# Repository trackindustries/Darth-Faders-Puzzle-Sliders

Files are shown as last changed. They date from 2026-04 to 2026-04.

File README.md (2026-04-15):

# Darth Faders Puzzle - Build/Install Guide
The Darth Faders Puzzle Trigger online guide explains in great detail the hardware, software and wiring for this project. We encourage you to read this first to get comfortable and familiar with the project and it's components.

## 3D Models
There are 7 pieces to the project
1. (1) Base
2. (1) Body
3. (1) Cap
4. (1) Crown
5. (3) Button Frames 

##Build
1. Install necessary library a board objects to Arduino IDE, and upload code to your RP2040.
2. Separate and pull apart all your jumper pins. (For example, you’ll need 4 each of Yellow, Red and Green, 4 Orange, 10 Black, 3 Brown, 1 Blue, 1 Purple, 1 White)
3. Remove the plastic housing from one side of each wire (use the tip of an exacto blade to lift up the small center tab and the casing slides right off). Then using your wire snips to snip off the aluminum pin just past the widest part closest to the wire. This will leave a short metal stub that will fit PERFECTLY inside the terminal holes. It create a tight and solid fit while keeping the integrity of the wire in tack and leave you with a sharp pin on the other to solder in all the through holes of the PCB’s and pins.
4. Solder your BUCK Converter to your Breakout board. Look at the bottom of your breakout to find the ground rail that runs across an entire row.f you put your 2 pin terminal block on that end and you place your buck just below that row, it’s easy to connect your OUT- and IN- to the GRN row and then up to one of your terminal pins. All that’s left is connecting OUT+ to USB hole, and IN+ up to the other pin on your terminal block.
5. Use volt meter to double check voltages. Should have 5v coming out of OUT+. OUT+ should be connected to USB. THIS IS CRITICAL. We do not want to connect the stack and later try to power the RP2040 with the 9v Power supply if this converter isn't properly connected!
6. Solder up your wires to your Sliders. I used colored wires on the center wiper pins so I could ensure I knew which slider goes to which color. Used Red for left pin (3.3v) and black or brown for GND pin up on the top side near the motor.
7. For each motor also use Black wire for one side and either a Red, Green or Yellow wire for the other pin. You will now have two Red, Yellow or Green wires coming off each slider/pot. One for the motor feather, and the other for A0, A1, and A2 pins on the breakout. 
8. Use small shrink tubes to keep things tidy. I used 3 (Top middle and bottom) to connect/group the 3 slider Grounds, 3 to group the 3.3v power lines, and 3 to connect each set of motor wires. This creates a sort of ‘slider chassy’ to keep your wires under control
9. Solder your Step Switches to their PCB Boards.  You’ll have 4 wires coming off each step switch PCB (A black LED-, a Brown Common and either RED, GREEN or YELLOW wires for both the LED+ and N-OPEN pins (mark the end of LED+ with black marker or piece of tape. I group the Commons together and the LED- wires Together. (Again using 3 small shrink tubs one near the pin connections to the PCB, one in the middle, then one near the other end (making sure not to get to close to the end as they need to separate) and do the same for the two colored wires ( LED+ and N-OPEN) from each button/PCB. (This is why we mark/identify the LED+ wire) 
10. Solder wires to your I2C backpack. Red Power, Black GND and Yellow and Orange for Clock and Data (or any other colors for that matter)
11. Now it’s time to wire it all up. Take extra care to get wires to the correct pins. They don't mark the breakout board with the RP2040 numbers so It takes effort to find the right one.
12. Use wire terminals to get your Ground wires down to three wires 
    1. Ground #1 (common lines from step switches
    2. Ground #2 (LED- lines from step switches, the GND line from momentary button and GND line if for your trigger line (if you need to access the trigger on success)
    3. Ground #3 (GND Lines from Sliders)
13. Use a wire terminal to group your 3.3v power lines from your sliders together 
    1. 3.3v #1 (power lines from the 3 sliders)
    2. 3.3v #2 (power line from I2C Backpack
14. Wire to breakout based on documentation leaving the 6 motor wires last (2 for each motor)
15. Plug RP2040 in to breakout.
16. Plug Motor Breakout in to RP2040.
17. Wire the motors to M1, M2 and M3 (Referring wiring diagram for proper terminals.
18. Screw the Motor ends of the sliders to the base of the model using M3x6 screws. Green left, Yellow Middle, Red right and set breakout on pins to hold in place.
19. Have Arduino IDE open with Serial Monitor set to 15500)
20. Ensure you have not yet connected your two 2 pin power terminals together (Motor breakout and BUCK). This will be the very last thing after all troubleshooting 
21. plug in 9v barrel 
22. Plug in USB-C.
23. Watch your Serial Monitor. Troubleshoot as needed (see troubleshooting section)
24. Once everything is working, unplug all power. Run wire from Motor Breakout + to + terminal connected to Buck. Do same for GND.
25. You should now be able to plug the 9v Barrel in and everything should run (you will not have access to serial monitor now). Run voltage tests on breakout (i.e. USB pin) with stack removed before connecting stack and powering by 9v to ensure 5v is being delivered to USB pin when 9v power is supplied to Motor breakout.
26. Finish assembly of model. Place BODY down in position of BASE
27. Pull the three button assemblies up though the top and screen in to place using M3x6 screws
28. Insert buttons in to openings of CROWN keeping color the same orientation as the sliders.
29. Use the Button frames to keep buttons in place using super glue as needed (TAKE EXTREME CARE to not get glue on button hinge, terminals or springs.
30. Use super glue to carefully glue CROWN to CAP TAKING EXTREME CARE not to use too much glue so that it seeps out edges. A few dots on each corner should be sufficient.
31. Glue Numeral Display to Backpack TAKING EXTREME CARE not to exceed past or overlap in the path of the Yellow slider path. 
32. Ta Da! Your done. Take pride in your Darth Faders Puzzle Trigger project.

## Lessons Learned
LESSONS LEARNED:

First, I was really struggling with the pins on the motorized sliders. Not sure why because looking at the data-sheet it’s very clear. I just saw other things that contradicted it and made it more complicated than it needed to be and they really don't articulate what pin is what in the Darth Faders project. Wont bore you with all the super gory many hours of details, but finally sorted it out. If you’re looking at the back of the slider with the motor at the top. The GROUND pin is on the top left side next to the motor (Strange place for it, but is what it is). The POWER pin is on the bottom left, the WIPER pin is in the middle, and the touch pin is on the bottom right (Not using this pin in my project). Do not swap the GND and POWER pins. If you do, the auto calibration routine on start up wont work right and you’ll get some cooky LED action happening. (PART OF MY STRUGGLE)

The breakout board has a 3 GND ports. We should use them all. Use a different GND port for each group of grounds. IN other words, put the 3 grounds for the step switch LED wires (along with the GND wires from the button and the Backpack) on one GND port, the 3 Common wires from the step switches on a separate GND port, and the ground wires from the sliders on a 3rd GND port. Don’t group all your ground wires together. You’ll get some icky LED wiper readings and Backpack LED behavior when you do that (PART OF MY STRUGGLE). 

This one is obvious but it’s worth a gentle reminder: Make sure you check all your solder points on your PB85 breakout boards for your switches, and make sure you use the Normally Open pin(NO-O).  The Normally Closed (NO-C) pin should be empty. (PART OF MY STRUGGLE) 

You must solder the A0 pins together on the backpack to change the address. If you don't, you’ll get a conflict with the motor breakout. The pins on the backpack go on the top when mounting in its opening on the model. (If you put it in upside down, the counter will go top to bottom instead of bottom to top. ) it’s designed so #1 is at the bottom and #24 is at the top. 

If you dig in to the code, you’ll may see there are some functions on the Motor.cpp file that aren’t used(tried cleaning them up). I tried to do some fancy slider dancing on a successful puzzle solve, but couldn’t get the sliders to get to the middle of the track correctly. I’m sure there was a better way of doing it, but just didn’t happen. As such the sliders do a quickly little UP->DOWN-> dance on success. 

IF you need to troubleshoot, MAKE SURE you don't have the BUCK converter powering your RP2040. You’ll need the 9v barrel power to power the motors and the USB-C plugged in to your RP2040 to see the serial port data. If you plug both of those in AND have the BUCK converter taking power from the 9V power and feeding the RP2040, you’ll make smoke and be sad.

I soldered the buck converter to the available breakout pins on the breakout board. It’s really nice they developed it so you can put additional components on the Breakout board when you need. (We need). I then used breadboard jumper wires to neatly connect things together. My soldering job was just pitiful but worked none the less. Soldering the BUCK to the Breakout makes things nice and tidy because we are going to have a *#&$^% ton of wires when this is all done. We don't need yet another object floating in space.

I put a 2 pin port block on the end of the breakout to give me easy access to IN power and ground on the BUCK
Soldered jumpers from one pin to IN+ and one pin to IN-
OUT- and IN- I ran to the GND rail that runs across the bottom (look at the bottom of the breakout board labeling to find it)
The OUT+ goes to USB.
I had to undo it once because I soldered things backwards. The BUCK is labeled on the bottom so when looking at another for reference, my brain flipped things and I soldered things wrong. (PART OF MY STRUGGLE) Now I just have to run to wires from the 2 pin Port Block on the Motor Breakout to the 2 pin Port block on the Bottom Breakout board. 
This means two wires are going in to the power Ports on the Motor Breakout. Coming IN from the Barrel port, the OUT to the BUCK.
I did all this so we could just use the 9V barrel power instead of needing both cables.

Make sure you use long enough wires to connect things together. You’ll board the struggle bus if things are too short or exactly the right length. Make things longer then user good wire management to clean things up (zip ties and heat shrink tubes)

##Troubleshooting

If your Backpack LED's are only lighting up a short distance:
 (i.e. only 6 high for example) you likely have your wiring wrong on your sliders. Check your ground connections, make sure the left wire is wired to 3.3v and GND to GND, and center pin is your wiper pin connect to the correct pin corresponding to that correct color. Also make sure on boot up that the High = Highst value, and Min = Lowest value. If these are backwards, things wont work.

If your LED Backpack matrix isn't working:
Make sure you have connected/soldered the A0 pins together on the back of the Backpack to change it's address. Out of the box, both it and the motor feather have the same I2C address.
Make sure you have Data to Data and Clock to Clock 

If your motors arn't working:
Make sure your motor feather has power (should have a green LED)
Make sure it's security stacked on top of your RP2040 (no pins are bent or missed their connection hole)
You have them connected to M1, M2 and M3 ports (GND wires should be in the middle connectors and the color wires (Red, Yellow and Green) should be on the outer ends.

If things don't work after connecting BUCK to breakout:
Remove the stack from the breakout.
You should have done a voltage test on the BUCK before you connected anything to it ensuring the OUT+ is sending 5v and that it's connected to USB.
Make sure you dont have solder gaps or bleeds.
Wire the 9v Barrel port directly to the breakout with the stack removed. Plug in the power and run your voltage tests again. IN+ should be 9v, OUT+ should be 5v.
Test the USB by connecting your probes to GND and the USB screw on the breakout. Should be 5v
Test to make sure you have connections between OUT+ and USB, as well as OUT- to ground.

## Quick Operation Reference

SET THE CODE
1. No step switches pressed + hold momentary 5s -> SET mode (all LEDs blink fast)
2. Press a step switch -> blinks slow -> move slider to select code -> bargraph fills that color
3. Press same switch again -> locked (LED solid, single bargraph LED lit)
4. Repeat for remaining two colors
5. Press momentary once -> saved -> celebration sequence -> IDLE

SOLVE THE PUZZLE
1. Press any step switch -> blinks slow (solve mode)
2. Move slider -> bargraph fills in that color
3. Press same switch -> locked (LED solid)
4. Repeat for other two colors (any order)
   CORRECT -> celebration + 3s HIGH on GPIO37
   WRONG   -> all off + sliders reset to bottom -> IDLE

REVEAL STORED CODE
1. Press each step step switch once -> all blink slow
2. Hold momentary 5s -> sliders move to stored positions, bargraph shows values
3. Press momentary once -> sliders return to bottom -> IDLE

FACTORY RESET
Hold momentary 10s (no switches in solve mode) -> code resets to 7/7/7 -> IDLE

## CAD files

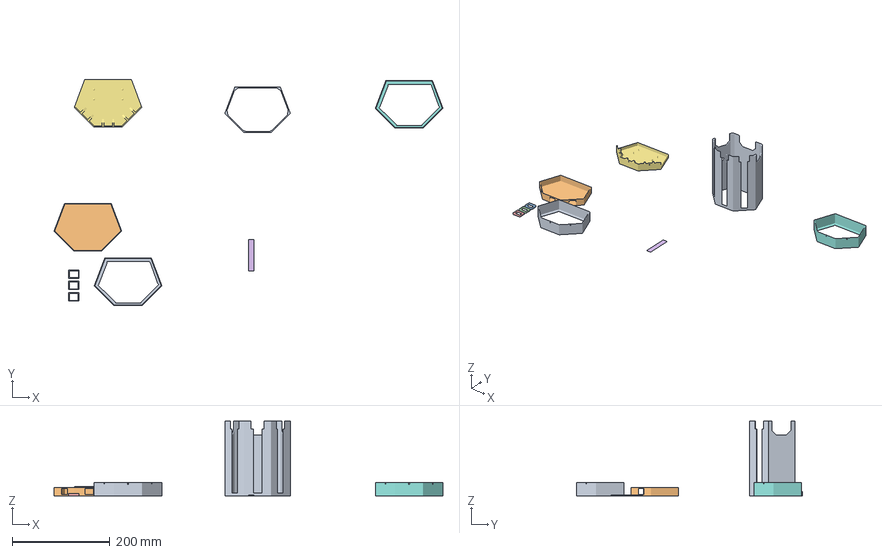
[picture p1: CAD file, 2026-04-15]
Darth_Fadters_Puzzle_Trigger.3mf
797.2 x 463.7 x 152.8 mm
fader_walls.stl
fader_top.stl x 3
Cube_A
fader_base.stl

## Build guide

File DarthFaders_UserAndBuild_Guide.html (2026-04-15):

Menu

# Darth Faders Puzzle/Trigger

A 3-slider motorized puzzle using a Feather RP2040, motorized slide potentiometers, a bi-color 24-bar bargraph, and color-coded step switches which trigger a 3.5v signal to a dedicated pin to initiate or trigger another device. We used this as a way to unlock a secret door in our home. You could also use this as a puzzle in an escape room. Based on the Adafruit Darth Faders project (https://learn.adafruit.com/darth-faders/build-the-darth-faders) by John Park. You can use that project for a guide to set up. We have not modified their 3D files, only added a top crown unit to hold the stepper switches and number plate for backpack. You can download the entire 3D print file bundle in our GitHub repository mentioned later in this project

CODE: C++ CONTROLER: Feather RP2040 LOE: High; 8+ Hrs 3D PRINTING: Yes SKILL LEVEL: Moderate

ℹ️

MOD/BRANCH IDEAS: The selected motorized sliders have a touch pin. This means if you utilized a capacitive slider knob, many of the functions which use the stepper switches could be eliminated simply by touching the slider.

🎛️

## Introduction

Three motorized sliders each represent a value from 1–24. Players must move each slider to the correct position and confirm it using the matching colored step switch. When all three values match the stored code, the puzzle triggers a success output on a designated GPIO pin.

An admin (momentary) button enables setting a new code, revealing the current code, and factory resetting — all without modifying firmware.

ℹ️

The solve code is stored in flash via the EEPROM library (built into the Arduino-Pico core) and survives power cycles and firmware re-uploads (unless you erase all flash).

🛒

## Bill of Materials

Materials below include Adafruit part numbers.

Feather RP2040

Main MCU. USB-C, 3.3V logic, I²C, ADC.

#4884

DC Motor + Stepper FeatherWing

I²C motor driver. M1=Red, M2=Green, M3=Yellow.

#2927

Motorized Slide Potentiometer

10kΩ pot + DC motor. Qty: 3.

#5466

Retro Step Switch with LED

One red, one green, one yellow. Qty: 3.

#5517

PB86 Step Switch Breakout PCB

Breakout board for each step switch. Qty: 3.

#5631

Bi-Color 24-Bar Bargraph I²C Backpack

I²C addr 0x70. Supports RED, GREEN, YELLOW.

#1721

Terminal Block Breakout FeatherWing

terminals for all signal connections.

#2926

DC Barrel Jack (2.1mm)

9V power input to Motor FeatherWing.

#610

9VDC 1000mA Power Adapter

Single power source for motors and board.

#63

MPM3610 5V Buck Converter

Steps 9V Power supply down to 5V.

#4739

Momentary Button

Hidden admin button for SET / REVEAL / RESET.

#1445

Stacking Headers

12-pin and 16-pin female headers

#2830

Potentiometer Nubbin

Rubber Slide Nubbin (pack of 3)

#5621

Resistors

100Ω resisters (use alternate valued resisters for brighter/dimmer LED's)

#4293

12" Jumper Wires

Primary wires for easy and secure component connections.

#760

Schematic

## Wiring Diagram



📦

## Libraries & Board Setup

Install the following via Arduino IDE → Tools → Manage Libraries:

Library | Notes
Adafruit Motor Shield V2 | Controls DC motors via I²C Motor FeatherWing
Adafruit LED Backpack Library | Drives the 24-bar bargraph display
Adafruit GFX Library | Dependency of LED Backpack
EEPROM | Built into Arduino-Pico core — no install needed. Stores solve code in flash.

For the board, install the Raspberry Pi Pico / RP2040 board package by Earle Philhower and select Adafruit Feather RP2040.

🔩

## Feather Stack Assembly

Stack the boards in this order, bottom to top, using stacking headers:

Position | Board | Adafruit # | Notes
Bottom | Terminal Block Breakout FeatherWing | #2926 | Provides screw terminals for all external wiring. 5V USB input from DC Buck converter to USB pin powers the RP2040.
Middle | Feather RP2040 | #4884 | MCU; USB-C for programming. Powered via Terminal Block USB pin in field.
Top | DC Motor + Stepper FeatherWing | #2927 | I²C motor driver; receives full 9V from barrel jack. This is placed on top for easy access to wire terminals

⚠️

Do not use the 9V power supply and the 5V USB at the same time when Feather Stack is assembled! You should use the USB-C for programming and/or troubleshooting, then switch to the 9V/BUCK input supply for field use, or disassemble Feather Stack to use both power sources.

🔌

## Pin Assignments

### Slider Potentiometers

Each motorized slider has 5 connections: Motor+, Motor–, Wiper (ADC), Track-Top (3.3V), Track-Bottom (GND).

Slider | Motor+ | Motor– | Wiper → RP2040 | Track Top | Track Bottom
Red | M1A | M1B | A0 [GPIO26] | 3.3V | GND
Green | M2A | M2B | A1 [GPIO27] | 3.3V | GND
Yellow | M3A | M3B | A2 [GPIO28] | 3.3V | GND

### Step Switches via PB86 Breakout

ℹ️

INPUT_PULLUP is enabled in firmware — no external pull-up resistors needed on switch pins. Add a 100–220Ω resistor in series with each LED+ line.

Switch | Input Pin (SW+) | LED Pin (LED+) | SW– / LED–
Red | D12 [GPIO12] | D11 [GPIO11] | GND
Green | D13 [GPIO13] | D9 [GPIO9] | GND
Yellow | D10 [GPIO10] | D6 [GPIO8] | GND

### Momentary Button

Connection | Pin
One leg | D5 [GPIO7]
Other leg | GND

### Bargraph I²C Backpack

Backpack Pin | RP2040 Pin
SDA | SDA [GPIO2]
SCL | SCL [GPIO3]
VCC | 3.3V
GND | GND

I²C address in use: 0x71 — set in config.h as BARGRAPH_ADDR.

⚠️

A0 solder jumper required. The backpack ships with a default address of 0x70, which conflicts with the DC Motor FeatherWing (#2927) on this build. To resolve this, bridge the A0 jumper on the back of the bargraph backpack — this shifts the address to 0x71, which is what BARGRAPH_ADDR in config.h is set to. If you ever swap or replace the backpack, remember to bridge A0 before powering up.

### Trigger Output (Correct Solve)

Signal | Default Pin | Behavior
Trigger | D24 [GPIO24] | HIGH for 3 seconds on correct solve

⚡

## Power

A single 9V barrel jack powers the entire project. A DC buck converter splits that supply into two paths — full 9V to the motor breakout board, and a regulated 5V to the RP2040.

Source | Connection | Powers
9V Barrel Jack | Motor FeatherWing VIN + GND | DC motors (full 9V)
9V Barrel Jack → Buck Converter → 5V out | USB port on Terminal Block FeatherWing | RP2040 + all logic
USB-C on RP2040 | Direct to RP2040 | Programming and development only

ℹ️

Buck converter setup: If using a multi variable output Buck converter, ensure you set to exactly 5V before connecting it to the Terminal Block USB input. Most Buck modules have a small trim potentiometer — use a multimeter to confirm the output voltage before plugging in the board.

⚠️

Do not use the 9V power supply and the 5V USB at the same time when Feather Stack is assembled! You should use the USB-C for programming and/or troubleshooting, then switch to the 9V/BUCK input supply for field use, or disassemble Feather Stack to use both power sources.

📐

## ADC Calibration

✅

No manual calibration required. The firmware automatically calibrates all three sliders on every boot — no measuring, no code changes, no re-uploading.

On every power-up, calibrateSliders() runs automatically inside puzzleInit() before the puzzle becomes active. It physically sweeps all three sliders through their full range, reads the real ADC values from your specific hardware, and sets the calibration range in memory. The puzzle then starts with accurate, hardware-matched calibration every single time.

### What you'll see on boot

1. All three sliders drive to the physical bottom simultaneously.
2. The bargraph fills red from top to bottom — confirming the low readings have been taken.
3. All three sliders drive to the physical top simultaneously.
4. The bargraph fills green from bottom to top — confirming the high readings have been taken.
5. All three sliders return to the bottom. Bargraph clears. Puzzle enters IDLE and is ready.

### How it works

The calibration sweep takes the lowest raw ADC reading across all three sliders at the bottom position and the highest reading at the top, then trims a ADC_CAL_MARGIN (50 counts) off each end as a safety buffer. The resulting values are stored in the runtime variables adcMin and adcMax, which readSlider() uses to map raw ADC values to the 1–24 step range.

If the calibration produces a degenerate result — for example if a motor isn't connected — the firmware falls back to the ADC_MIN_DEFAULT / ADC_MAX_DEFAULT constants in config.h and logs a warning to Serial.

### Verifying calibration via Serial Monitor

Open Serial Monitor at 115200 baud during boot to see the raw readings for each slider and the final computed range:

Serial Monitor — calibration output

[Cal] Starting auto-calibration...
[Cal] Low raw[0] = 42
[Cal] Low raw[1] = 38
[Cal] Low raw[2] = 45
[Cal] High raw[0] = 4051
[Cal] High raw[1] = 4043
[Cal] High raw[2] = 4058
[Cal] adcMin=88  adcMax=3993
[Cal] Calibration complete

⚠️

If you see [Cal] WARNING: bad calibration range in Serial output, check that all three motor wires are connected and the 9V supply is present before the RP2040 boots.

📁

## Files & Model

All files live in the same folder — no subfolders. The folder name must match the .ino filename exactly.

Download firmware & 3D Models in our GitHub repository. GitHub

darth_faders_puzzle/

darth_faders_puzzle.ino ← entry point: setup() and loop()

config.h ← all pins, timing, ADC constants

motors.h / motors.cpp ← Motor FeatherWing abstraction

bargraph.h / bargraph.cpp ← 24-bar bargraph display driver

switches.h / switches.cpp ← switch debounce, LED blink engine

puzzle.h / puzzle.cpp ← full puzzle state machine

WIRING_AND_SETUP.md ← wiring reference

🔄

## State Machine

STATE_IDLE → STATE_SOLVE → STATE_SUCCESS / STATE_FAIL

STATE_IDLE → STATE_SET → STATE_SET_COLOR → confirm → STATE_IDLE

STATE_SOLVE → all 3 active + hold 5s → STATE_REVEAL → press → STATE_IDLE

State | Step Switch LEDs | Bargraph | Sliders
STATE_IDLE | All off | Off | Bottom (pos 1)
STATE_SOLVE | Active color blinks slow; locked color solid | Active color fills 1→N as slider moves | Active slider free to move
STATE_SET | Unset colors blink fast; set colors solid | Shows confirmed positions | Free
STATE_SET_COLOR | Active color blinks slow | Active color fills 1→N | Active slider free
STATE_REVEAL | All blink slow | All 3 solve values shown in color | Move to stored code positions
STATE_SUCCESS | All very-fast-flash 4s → off | Spectrum sweep (red/green/yellow) bounces top↔bottom | Center→Top→Bottom→Top→Bottom
STATE_FAIL | All off | Off | Return to bottom

📖

## Module API Reference

### motors.h

Function | Description
motorsInit() | Initializes Motor FeatherWing over I²C
motorBrake(ch) | Immediately brakes motor on channel 1–3
motorToTop(ch) | Open-loop: runs motor up until top end-stop
motorToBottom(ch) | Open-loop: runs motor down to bottom
motorToCenter(ch) | Open-loop: moves to approximate center
allMotorsToTop/Bottom/Center() | Runs all three simultaneously
motorMoveToValue(ch, pin, val, adcMin, adcMax) | Closed-loop: drives until ADC reads val (1–24), 5s timeout
allMotorsMoveToValues(pinR, valR, pinG, valG, pinY, valY, adcMin, adcMax) | Closed-loop: drives all three motors simultaneously to target values, 5s timeout

### bargraph.h

Function | Description
bargraphInit() | Initializes backpack at BARGRAPH_ADDR
bargraphClear() | Turns all 24 LEDs off
bargraphShowValue(val, color) | Fills LEDs 1..val with color (BAR_RED/GREEN/YELLOW)
bargraphShowSingle(pos, color) | Lights single LED at position 1–24
bargraphShowLocked(r, g, y) | Shows up to 3 pinned LEDs; handles alternating if shared
bargraphSetAlternating(pos, c1, c2) | Makes a LED alternate between two colors at ALT_COLOR_MS
bargraphUpdate() | Must be called every loop() to drive alternating animation
bargraphShowSpectrum(fillTo) | Fills LEDs 1..fillTo cycling red/green/yellow — used for success and factory reset animations

### switches.h

Function | Description
switchesInit() | Configures all switch and LED pins
switchesUpdate() | Must be called every loop() — debounce + blink engine
switchPressed(idx) | Returns true once on falling edge (0=Red, 1=Green, 2=Yellow)
momentaryPressed() | Returns true once on momentary button falling edge
momentaryHeld(&ms) | Returns true while held; fills ms with elapsed hold time
switchSetLed(idx, mode) | LED_OFF / LED_ON / LED_BLINK_SLOW / LED_BLINK_FAST / LED_BLINK_VFAST

🔐

## Setting the Solve Code

ℹ️

Prerequisite: No step switches may be in solve mode (all LEDs off) when you begin the hold.

1. Hold the momentary button for 5 seconds → enters SET mode. All three step switch LEDs blink fast.
2. Press any step switch (e.g. Red) → its LED changes to slow blink, indicating you are now setting that color's value.
3. Move that slider up or down → the bargraph fills in the corresponding color, showing the current value (1–24).
4. Press the same step switch again → value is locked. LED goes solid. Bargraph shows a single LED at the locked position.
5. Repeat steps 2–4 for the remaining two colors. When each is set its LED is solid; unset colors continue to blink fast.
6. If two colors share the same value, the bargraph LED at that position will alternate between both colors every 500ms.
7. Once all three LEDs are solid, press the momentary button once → code is saved to EEPROM flash → celebration sequence plays → puzzle returns to IDLE.

🧩

## Solving the Puzzle

1. From IDLE, press any step switch → its LED blinks slow (that color is now in solve mode).
2. Move that slider → the bargraph fills in that color, showing position 1–24 in real time.
3. Press the same switch again → value locked. LED goes solid.
4. Repeat for the other colors in any order. Additional colors can be placed in solve mode at any time by pressing their switch.
5. When all three LEDs are solid, the code is evaluated automatically.

### ✅ Correct Code

All LEDs flash very fast for 4 seconds → sliders perform victory dance (Center → Top → Bottom → Top → Bottom) → D24 (GPIO24) goes HIGH for 3 seconds → puzzle returns to IDLE.

### ❌ Wrong Code

All LEDs go off → bargraph clears → all sliders return to the bottom (position 1) → puzzle returns to IDLE.

👁️

## Reveal Mode

Allows the puzzle operator to view the currently stored solve code without resetting it.

1. Press all three step switches (any order) so all three LEDs are blinking slowly.
2. Hold the momentary button for 5 seconds → enters REVEAL mode.
3. All three sliders motor to their stored solve positions. The bargraph displays all three values in their respective colors.
4. Press the momentary button once → all LEDs turn off, sliders return to bottom, bargraph clears, puzzle returns to IDLE.

🔄

## Factory Reset

⚠️

The stored solve code will be overwritten with 7 / 7 / 7.

1. Ensure the puzzle is in IDLE state with all step switch LEDs off (no switches in solve mode).
2. Hold the momentary button for 10 seconds.
3. After 5 seconds you will be in SET mode — the step switch LEDs will start to flash rapidly. Continue holding the button down for another 5 seconds until the bargraph illuminates.
4. A spectrum bargraph sweep plays (top to bottom, then bottom to top) → solve code resets to 7/7/7 in EEPROM → puzzle returns to IDLE.

🖥️

## Serial Debug Output

Open Serial Monitor at 115200 baud. Expected startup output:

⚠️

Ensure the Buck Converter is NOT connected to your breakout board when using two power sources. During troubleshooting you must power the motor breakout using the 9V barrel plug, and the USB-C to power the Feather RP2040. This gives you access to the Serial Monitor but also power to the motors WITHOUT the two power sources connected. You will connect the buck to the breakout when you're ready for field/production use.

Serial Monitor — startup

[DarthFaders] Boot
[Motors] OK
[Bargraph] OK
[Switches] OK
[Puzzle] Code: R=7 G=7 Y=7
[Cal] Starting auto-calibration...
[Cal] Low raw[0] = 42
[Cal] Low raw[1] = 38
[Cal] Low raw[2] = 45
[Cal] High raw[0] = 4051
[Cal] High raw[1] = 4043
[Cal] High raw[2] = 4058
[Cal] adcMin=88  adcMax=3993
[Cal] Calibration complete
[Puzzle] -> IDLE
[Puzzle] Init complete
[DarthFaders] Ready

Message | Meaning
[Cal] Starting auto-calibration... | Boot-time slider sweep has begun
[Cal] Low raw[N] = N | Raw ADC reading at bottom position for each slider (0=Red, 1=Green, 2=Yellow)
[Cal] High raw[N] = N | Raw ADC reading at top position for each slider
[Cal] adcMin=N adcMax=N | Final calibrated range after margin is applied — this is what the puzzle uses
[Cal] WARNING: bad calibration range | Calibration produced invalid values — check motor wiring and 9V supply; fallback defaults used
[Puzzle] EEPROM not initialised — using defaults | First boot on fresh hardware — no saved code found, defaults (7/7/7) used
[Puzzle] Code: R=N G=N Y=N | Solve code loaded from EEPROM on boot
[Puzzle] Color N -> solve mode | A step switch was pressed; entering solve mode for that color
[Puzzle] Color N locked at N | Second press on a step switch; value confirmed
[Puzzle] -> SUCCESS | All three values match the stored code
[Puzzle] -> FAIL | One or more values did not match
[Puzzle] -> SET | Entered SET mode after 5s hold
[Puzzle] Code saved: R=N G=N Y=N | New solve code written to EEPROM flash
[Puzzle] FACTORY RESET | 10s hold triggered; code reset to 7/7/7
[Motors] MotorShield not found! | I²C wiring issue — check SDA/SCL and power to Motor FeatherWing

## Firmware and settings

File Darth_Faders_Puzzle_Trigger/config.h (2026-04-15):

#pragma once

// ── Board: Adafruit Feather RP2040 (#4884) ────────────────────────────────────

// ── Slider ADC pins (wiper of each motorized fader) ──────────────────────────
#define PIN_SLIDER_R   A0   // GPIO26
#define PIN_SLIDER_G   A1   // GPIO27
#define PIN_SLIDER_Y   A2   // GPIO28

// ── Step switch input pins (active-LOW, internal pull-up enabled) ─────────────
#define PIN_SW_RED     12   // D12 / GPIO12
#define PIN_SW_GREEN   13   // D13 / GPIO13
#define PIN_SW_YELLOW  10   // D10 / GPIO10

// ── Step switch LED output pins ───────────────────────────────────────────────
#define PIN_LED_RED    11   // D11 / GPIO11 
#define PIN_LED_GREEN   9   // D9  / GPIO9
#define PIN_LED_YELLOW  8   // D6  / GPIO8

// ── Momentary button (active-LOW, internal pull-up enabled) ──────────────────
#define PIN_MOMENT_BTN  7   // D5  / GPIO7  
// ── Trigger output pin (HIGH for TRIGGER_DURATION_MS on correct solve) ────────────────────────
#define PIN_TRIGGER    24   // D24 / GPIO24  

// ── Motor FeatherWing channel assignments (M1-M3) ─────────────────────────────
#define MOTOR_CH_RED    1
#define MOTOR_CH_GREEN  2
#define MOTOR_CH_YELLOW 3

// ── Bargraph I2C address (default 0x70) ───────────────────────────────────────
// Solder A0 Bridge on back of bargraph
// I2C on RP2040 Feather: SDA=GPIO2, SCL=GPIO3 — Wire.begin() handles this automatically
#define BARGRAPH_ADDR  0x71

// ── Timing constants (ms) ─────────────────────────────────────────────────────
#define HOLD_SET_MS          5000
#define HOLD_RESET_MS       10000
#define BLINK_FAST_MS         100
#define BLINK_SLOW_MS         500
#define BLINK_VERY_FAST_MS     60
#define ALT_COLOR_MS          500
#define SUCCESS_BLINK_MS     4000
#define TRIGGER_DURATION_MS  3000

// ── Motor settings ────────────────────────────────────────────────────────────
#define MOTOR_SPEED_NORMAL  180
#define MOTOR_SPEED_SLOW    120
#define MOTOR_SETTLE_MS     120

// ── ADC auto-calibration ──────────────────────────────────────────────────────
// ADC_MIN_DEFAULT / ADC_MAX_DEFAULT are fallback values only.
// On every boot, calibrateSliders() in puzzle.cpp performs a live sweep and
// overwrites the runtime adcMin / adcMax variables automatically.
// RP2040 ADC is also 12-bit (0-4095) so defaults remain the same.
#define ADC_MIN_DEFAULT    100
#define ADC_MAX_DEFAULT   3900
#define ADC_CAL_MARGIN      50   // Safety margin trimmed from each end after sweep
#define CAL_SETTLE_MS      300   // Extra settle time after motor stops before reading
#define SLIDER_STEPS        24

// ── EEPROM layout  ────────────────────
// 3 bytes starting at address 0: R, G, Y solve code values
#define EEPROM_SIZE         4    // bytes allocated (3 data + 1 validity flag)
#define EEPROM_VALID_FLAG   0xA5 // written to byte 3 to confirm data is initialised
#define EEPROM_ADDR_R       0
#define EEPROM_ADDR_G       1
#define EEPROM_ADDR_Y       2
#define EEPROM_ADDR_FLAG    3

// ── Default solve code (restored on factory reset) ───────────────────────────
#define DEFAULT_SOLVE_R   7
#define DEFAULT_SOLVE_G   7
#define DEFAULT_SOLVE_Y   7

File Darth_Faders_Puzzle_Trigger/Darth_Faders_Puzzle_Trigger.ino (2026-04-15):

/*
 * Darth Faders Puzzle
 * Hardware:
 *   Adafruit Feather RP2040 (#4884)
 *   3x Motorized Slide Potentiometers (#5466)
 *   DC Motor + Stepper FeatherWing (#2927)
 *   Terminal Block Breakout FeatherWing (#2926)
 *   Bi-Color 24-Bar Bargraph I2C Backpack (#1721)
 *   3x Retro Step Switches with LED (#5517) on PB86 boards (#5631)
 *   1x Momentary Button (#1445)
 *
 * Board: Adafruit Feather RP2040 (via Adafruit RP2040 board package)
 *
 * Required Libraries (install via Library Manager):
 *   - Adafruit Motor Shield V2
 *   - Adafruit LED Backpack Library
 *   - Adafruit GFX Library
 *   - EEPROM (built into Arduino-Pico core — no install needed)
 */

#include <Wire.h>
#include <EEPROM.h>
#include "config.h"
#include "motors.h"
#include "bargraph.h"
#include "switches.h"
#include "puzzle.h"

void setup() {
Serial.begin(115200);
while (!Serial && millis() < 3000);
delay(100);
Serial.println("[DarthFaders] Boot");
  Wire.begin();
  motorsInit();
  bargraphInit();
  switchesInit();
  puzzleInit();
  Serial.println("[DarthFaders] Ready");
}


void loop() {
puzzleUpdate();
}

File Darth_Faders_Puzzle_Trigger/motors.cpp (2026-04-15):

#include "motors.h"
#include "config.h"
#include <Adafruit_MotorShield.h>

static Adafruit_MotorShield AFMS;
static Adafruit_DCMotor* motors[4]; // index 0 unused; 1-3 active

// ── Direction defines ─────────────────────────────────────────────────────────
// Sliders are mounted with motors at the BOTTOM.
// Physical bottom (motor end) = FORWARD, Physical top = BACKWARD
#define MOTOR_DIR_BOTTOM  FORWARD
#define MOTOR_DIR_TOP     BACKWARD

void motorsInit() {
  AFMS = Adafruit_MotorShield();
  if (!AFMS.begin()) {
    Serial.println("[Motors] MotorShield not found! Check I2C.");
    while (1) delay(10);
  }
  for (int i = 1; i <= 3; i++) {
    motors[i] = AFMS.getMotor(i);
    motors[i]->setSpeed(0);
    motors[i]->run(RELEASE);
  }
  Serial.println("[Motors] OK");
}

void motorBrake(uint8_t ch) {
  if (ch < 1 || ch > 3) return;
  motors[ch]->run(BRAKE);
  motors[ch]->setSpeed(0);
}

void motorToTop(uint8_t ch) {
  if (ch < 1 || ch > 3) return;
  motors[ch]->setSpeed(MOTOR_SPEED_NORMAL);
  motors[ch]->run(MOTOR_DIR_TOP);
  delay(MOTOR_SETTLE_MS * 2);
  motorBrake(ch);
}

void motorToBottom(uint8_t ch) {
  if (ch < 1 || ch > 3) return;
  motors[ch]->setSpeed(MOTOR_SPEED_NORMAL);
  motors[ch]->run(MOTOR_DIR_BOTTOM);
  delay(MOTOR_SETTLE_MS * 2);
  motorBrake(ch);
}

void motorToCenter(uint8_t ch) {
  motorToBottom(ch);
  delay(100);
  motors[ch]->setSpeed(MOTOR_SPEED_NORMAL);
  motors[ch]->run(MOTOR_DIR_TOP);
  delay(MOTOR_SETTLE_MS);
  motorBrake(ch);
}

void allMotorsToTop() {
  for (int i = 1; i <= 3; i++) {
    motors[i]->setSpeed(MOTOR_SPEED_NORMAL);
    motors[i]->run(MOTOR_DIR_TOP);
  }
  delay(MOTOR_SETTLE_MS * 2);
  for (int i = 1; i <= 3; i++) motorBrake(i);
}

void allMotorsToBottom() {
  for (int i = 1; i <= 3; i++) {
    motors[i]->setSpeed(MOTOR_SPEED_NORMAL);
    motors[i]->run(MOTOR_DIR_BOTTOM);
  }
  delay(MOTOR_SETTLE_MS * 2);
  for (int i = 1; i <= 3; i++) motorBrake(i);
}

void allMotorsToCenter() {
  allMotorsToBottom();
  delay(100);
  for (int i = 1; i <= 3; i++) {
    motors[i]->setSpeed(MOTOR_SPEED_NORMAL);
    motors[i]->run(MOTOR_DIR_TOP);
  }
  delay(MOTOR_SETTLE_MS);
  for (int i = 1; i <= 3; i++) motorBrake(i);
}

void motorMoveToValue(uint8_t ch, uint8_t pinADC, uint8_t targetValue, int adcMin, int adcMax) {
  if (ch < 1 || ch > 3) return;
  uint32_t timeout = millis() + 5000;
  while (millis() < timeout) {
    int raw     = analogRead(pinADC);
    int current = map(constrain(raw, adcMin, adcMax), adcMin, adcMax, 1, SLIDER_STEPS);
    if (abs(current - (int)targetValue) <= 1) { motorBrake(ch); return; }
    motors[ch]->setSpeed(MOTOR_SPEED_SLOW);
    motors[ch]->run((current < (int)targetValue) ? MOTOR_DIR_TOP : MOTOR_DIR_BOTTOM);
    delay(20);
  }
  motorBrake(ch);
}

void allMotorsMoveToValues(uint8_t pinR, uint8_t valR,
                           uint8_t pinG, uint8_t valG,
                           uint8_t pinY, uint8_t valY,
                           int adcMin, int adcMax) {
  bool doneR = false, doneG = false, doneY = false;
  uint32_t timeout = millis() + 5000;
  while (millis() < timeout) {
    if (!doneR) {
      int cur = map(constrain(analogRead(pinR), adcMin, adcMax), adcMin, adcMax, 1, SLIDER_STEPS);
      if (abs(cur - (int)valR) <= 1) { motorBrake(1); doneR = true; }
      else { motors[1]->setSpeed(MOTOR_SPEED_SLOW); motors[1]->run(cur < (int)valR ? MOTOR_DIR_TOP : MOTOR_DIR_BOTTOM); }
    }
    if (!doneG) {
      int cur = map(constrain(analogRead(pinG), adcMin, adcMax), adcMin, adcMax, 1, SLIDER_STEPS);
      if (abs(cur - (int)valG) <= 1) { motorBrake(2); doneG = true; }
      else { motors[2]->setSpeed(MOTOR_SPEED_SLOW); motors[2]->run(cur < (int)valG ? MOTOR_DIR_TOP : MOTOR_DIR_BOTTOM); }
    }
    if (!doneY) {
      int cur = map(constrain(analogRead(pinY), adcMin, adcMax), adcMin, adcMax, 1, SLIDER_STEPS);
      if (abs(cur - (int)valY) <= 1) { motorBrake(3); doneY = true; }
      else { motors[3]->setSpeed(MOTOR_SPEED_SLOW); motors[3]->run(cur < (int)valY ? MOTOR_DIR_TOP : MOTOR_DIR_BOTTOM); }
    }
    if (doneR && doneG && doneY) return;
    delay(20);
  }
  // Timeout — brake any that didn't finish
  if (!doneR) motorBrake(1);
  if (!doneG) motorBrake(2);
  if (!doneY) motorBrake(3);
}
